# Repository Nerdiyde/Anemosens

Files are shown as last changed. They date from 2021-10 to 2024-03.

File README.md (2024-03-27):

# Anemosens

Anemosens is an 3D printable anemometer that mostly consists of SLA printed parts.

  **Meanwhile I improved the initial design files. The latest design files are available here:**
     https://nerdiy.de/de_de/produkt/anemosens-v1-1-teile-fuer-3d-druckbares-anemometer-3d-druckbar-stl-dateien/

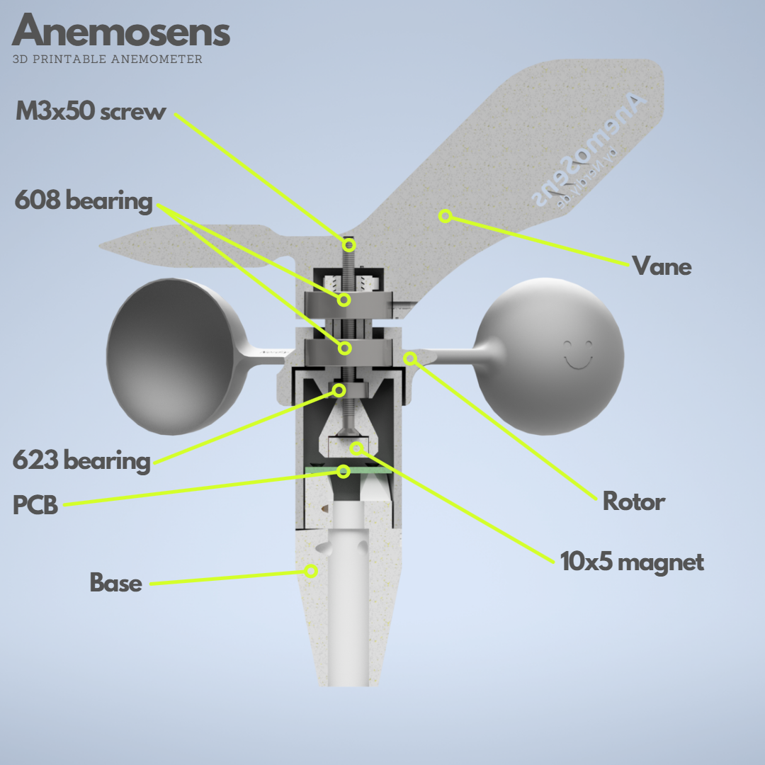
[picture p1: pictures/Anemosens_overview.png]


## Detailed build guide

**You can find more information and detailed HowTo's in the following articles:**

- [Anemosens - Build a 3D printed wind sensor / anemometer](https://nerdiy.de/en/howto-anemosens-ein-3d-gedruckten-windsensor-anemometer-aufbauen/)

Anemosens_Video (https://www.youtube.com/watch?v=w3RU5c9Zf3Q)

## MCU PCB

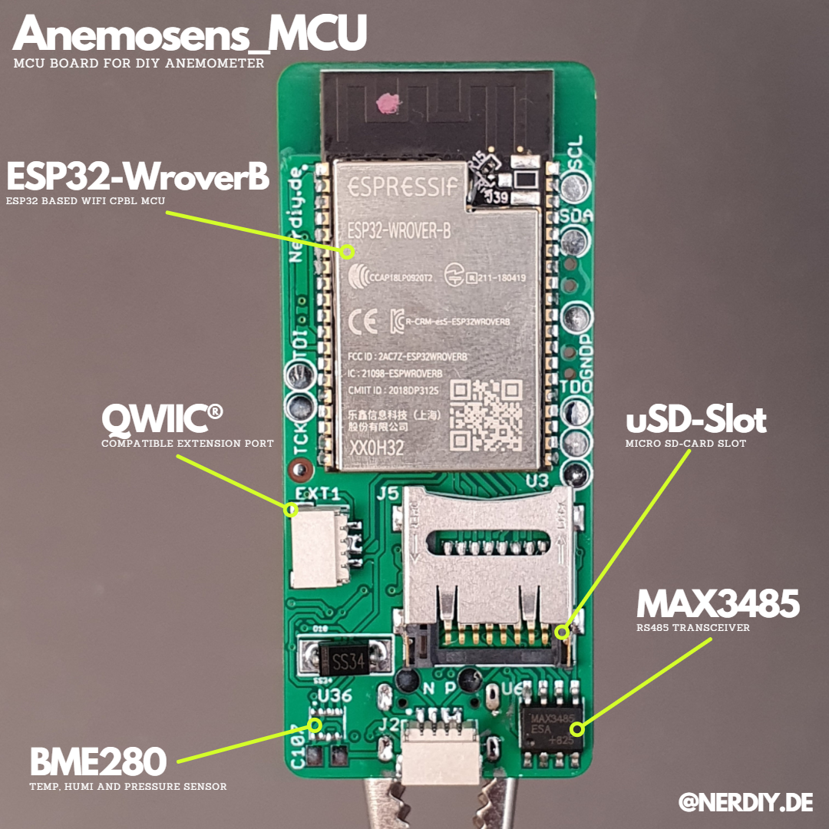
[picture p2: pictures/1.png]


Thanks to the MCU Board it will be possible to use Anemosens as a standalone Anemometer that can be used for long time observations in remote areas (therefore the microSD-card slot) or just as one part of your weatherstation (therefore the RS485 interface).

The RS485 interface is used to make the measured data available via Modbus. This way you can connect the Anemometer easily to your RaspberryPi, PC or many other platforms that support RS485/Modbus.

Additionally you can activate a serial-stream of the data (packed as handy JSON) via the USB connection.

Last but not least the integrated ESP32 also opens a BLE Server. Thanks to this you also have the possibility to pull the data wirelessly using your smartphone or computer.

Of course you can also write your own firmware and program it via the integrated USB-C port. The QWIIC-port makes it easy to connect additional sensors via I2C.

**You can find more information about the sensor pcb in the following article:**

- [PCB - Assembly of the Anemosens_MCU PCB](https://nerdiy.de/en/howto-pcb-anemosens_mcu-pcb-aufbauen/)

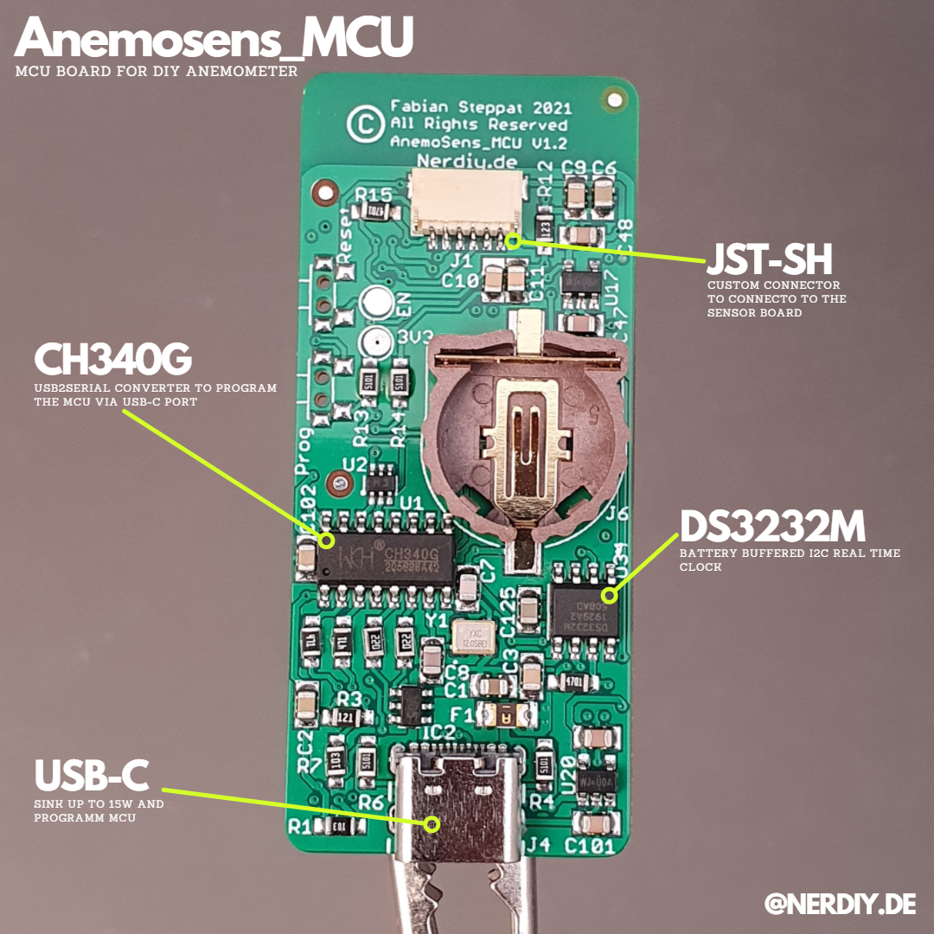
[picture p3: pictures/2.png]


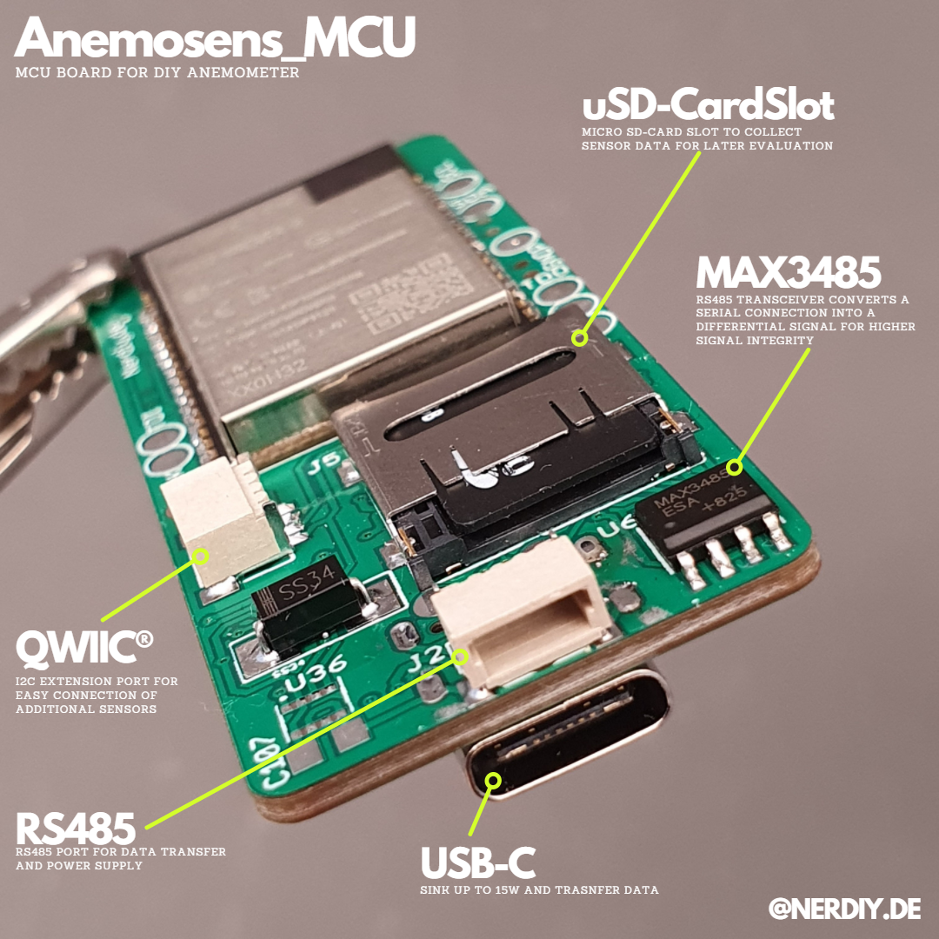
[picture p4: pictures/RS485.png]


## Sensor PCB

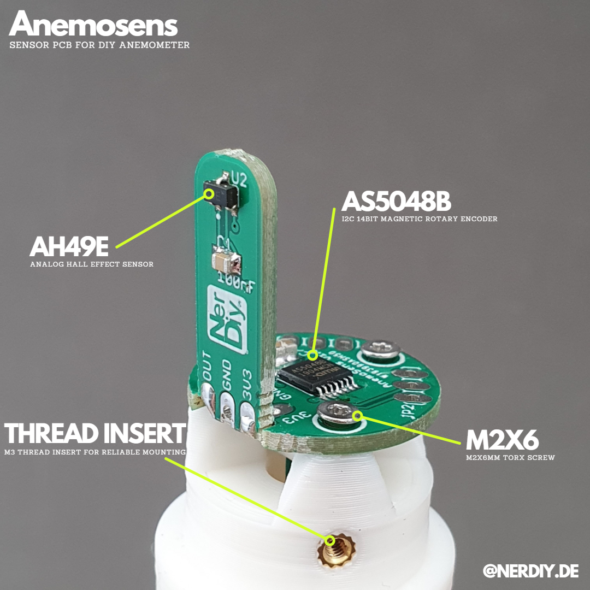
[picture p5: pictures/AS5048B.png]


The Anemosens sensor PCB is the basis for the sensor assembly of Anemosens, a 3D printed anemometer that I developed for the second version of WinDIY. (article here: **_[https://nerdiy.de/en/howto-pcb-das-anemosens-sensor-pcb-aufbauen//](https://nerdiy.de/en/howto-pcb-das-anemosens-sensor-pcb-aufbauen/)_**).

For this purpose, an AH49E Hall sensor and an AS5048B I2C 14 bit magnetic rotary encoder are installed on the PCB. The AS5048B is used to determine the wind direction. With the help of the AH49E Hall sensor you can measure the wind speed by measuring the time of one complete revolution of the wind blades.

To finish the assembly of the PCB you need to divide it into two parts and solder it together at a 90� angle. The finished PCB can then mounted into the 3D printed housing from Anemosens and fixed with three M2x6 screws.

**You can find more information about the sensor pcb in the following article:**

- [PCB - Assemble the Anemosens sensor PCB](https://nerdiy.de/en/howto-pcb-das-anemosens-sensor-pcb-aufbauen/)

### Trademarks

All third-party trademarks are the property of their respective owners. More infos here: https://nerdiy.de/en/warenzeichen/

### License

Unless otherwise stated, all works presented here and on Nerdiy.de that are not based on software/code are subject to the CC BY-NC-SA 4.0 license (attribution - non-commercial - dissemination under the same conditions 4.0 international).

You can find additional infos here: https://nerdiy.de/en/lizenz/

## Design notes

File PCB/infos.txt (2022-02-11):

Additonal build instructions:

MCU PCB:
English: https://nerdiy.de/en/howto-pcb---anemosens_mcu-pcb-aufbauen/
German: https://nerdiy.de/howto-pcb---anemosens_mcu-pcb-aufbauen/

Sensor PCB:
English: https://nerdiy.de/en/howto-pcb-das-anemosens-sensor-pcb-aufbauen/
German: https://nerdiy.de/howto-pcb-das-anemosens-sensor-pcb-aufbauen/

The PCBs can be ordered at:
https://www.pcbway.com/project/shareproject/Anemosens_MCU.html
https://www.pcbway.com/project/shareproject/Anemosens_sensor_PCB.html

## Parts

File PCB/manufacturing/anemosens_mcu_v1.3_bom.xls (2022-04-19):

PCBWay Bom Quotation, Product No.:T-1C4W457044A
Item # | *Designator | *Qty | Manufacturer | *Mfg Part # | Description / Value | *Package/Footprint | *Unit Price(5 sets) | *Total | *Delivery Time | *Actual Purchase Mfg Part # | *PCBWay Note | Customer Reply | PCBWay Update | Comment
1 | C2,C3,C9,C10,C102,C107,C125 | 7 |  |  | 100nF | C0805K | $0.031 | $1.085 |  | CL21B104KCFNNNE | 『 』
2 | C47,C48,C101,C103 | 4 |  |  | 1µF | C0805K | $0.029 | $0.580 |  | CL21B105KBFNNNE | 『 』
3 | C1,C6 | 2 |  |  | 10uF | C0805K | $0.060 | $0.600 |  | CL21A106KOQNNNE | 『 』
4 | C7,C8 | 2 |  |  | 22pF | C0805K | $0.074 | $0.740 |  | CL21C220JBANNNC | 『 』
5 | C11 | 1 |  |  | 1nF | C0805K | $0.242 | $1.210 |  | CL21C102JBCNNNC | 『 』
6 | R1,R7 | 2 |  |  | 10k | R0805W | $0.030 | $0.300 |  | RC0805FR-0710KL | 『 』
7 | R4,R6 | 2 |  |  | 5,1k | R0805W | $0.031 | $0.310 |  | RC0805FR-075K1L | 『 』
8 | R10,R11 | 2 |  |  | 66 | R0805W | $0.031 | $0.310 |  | RC0805FR-0766RL | 『 』
9 | R13,R14 | 2 |  |  | 5k | R0805W | $0.031 | $0.310 |  | RC0805FR-075KL | 『 』
10 | R15,R16 | 2 |  |  | 4k7 | R0805W | $0.035 | $0.350 |  | RC0805FR-074K7L | 『 』
11 | R45,R47 | 2 |  |  | 470 | R0805W | $0.032 | $0.320 |  | RC0805FR-07470RL | 『 』
12 | R3 | 1 |  |  | 120 | R0805W | $0.066 | $0.330 |  | RC0805FR-07120RL | 『 』
13 | R12 | 1 |  |  | 12k | R0805W | $0.050 | $0.250 |  | RC0805FR-0712KL | 『 』
14 | D10 | 1 | MDD | SS34 | SS34 | SMADIODE | $0.110 | $0.550 |  |  | 『 』
16 | U36 | 1 |  | BME280 | BME280 | PSON65P250X250X100-8N | $7.700 | $38.500 |  |  | 『 』[Price is changing higher, final price should be subjected to the real price when order!] |  |  | Optional: Only needed if measurement of temperature, humidity and air pressure is needed
17 | U$22,U$23 | 2 |  |  | SMT2X4MMTACTILE_PUSH_BUTTON | SMT2X4MMTACTILE_PUSH_BUTTON |  |  |  |  | 『 』Please provide exact part number or component URL. |  |  | Optional: Only needed if programming of the ESP32 is done manually (not via the USB-C connection)
18 | U6 | 1 |  | MAX3485ESA+ | MAX3485ESA+ | SOIC127P600X175-8N | $1.470 | $7.350 |  |  | 『 』 |  |  | Optional: Only needed if communication via rs485/modbus is needed
19 | U34 | 1 |  | DS3232M | DS3232M | SOIC127P600X175-8N | $9.500 | $47.500 |  |  | 『 』[Price is changing higher, final price should be subjected to the real price when order!] |  |  | Optional: Only needed for Timekeeping if data logging on locally connected micro SD card is needed
20 | U1 | 1 |  | CH340G | CH340G | SOIC16 | $0.825 | $4.125 |  |  | 『 』
21 | U2 | 1 |  | UMH3N | UMH3N | SOP65P210X100-6N | $0.156 | $0.780 |  |  | 『 』
22 | U17,U20 | 2 |  | RT9013 | RT9013 | SOT23-5 | $0.417 | $4.170 |  | RT9013-33GB | 『 』
23 | U3 | 1 |  | ESP32-WROVER-B | ESP32-WROVER-B | XCVR_ESP32-WROVER-B_(16MB) | $5.360 | $26.800 |  | ESP32-WROVER-B(16MB) | 『 』[Price is changing higher, final price should be subjected to the real price when order!]
24 | Y1 | 1 |  | ABM8AIG-12.000MHZ-12-2Z-T3 | ABM8AIG-12.000MHZ-12-2Z-T3 | OSCSC320X250X100N | $1.308 | $6.540 | 7-10 Workdays |  | 『 』
25 | F1 | 1 |  | 1206L200PR | 4A | PTC-1206-WIDE |  |  |  |  | 『 』
26 | EXT1 | 1 |  | SM04B-SRSS-TB(LF)(SN) | MICROBUILDER_STEMMA_I2C_QT | JST_SM04B-SRSS-TB(LF)(SN) |  |  |  |  | 『 』
28 | IC2 | 1 | TECH PUBLIC | SRV05-4 | SRV05-4 | TSOP-6.PAC | $0.152 | $0.760 |  |  | 『 』
29 | J4 | 1 |  | USB4105_REVA | USB4105_REVA | GCT_USB4105_REVA | $1.059 | $5.295 | 7-10 Workdays | USB4105-GF-A | 『 』
30 | J2 | 1 |  | SM04B-SRSS-TB(LF)(SN) | SM04B-SRSS-TB(LF)(SN) | JST_SM04B-SRSS-TB(LF)(SN) | $0.260 | $1.300 |  |  | 『 』 |  |  | Optional: Only needed if communication via rs485/modbus is needed
31 | J1 | 1 |  | SM06B-SRSS-TB(LF)(SN) | SM06B-SRSS-TB(LF)(SN) | JST_SM06B-SRSS-TB(LF)(SN) | $0.552 | $2.760 |  |  | 『 』
32 | J6 | 1 |  | BC501SM-TR | BC501SM-TR | MPD_BC501SM-TR | $1.714 | $8.570 | 7-10 Workdays |  | 『 』
33 | J5 | 1 |  | MEM2067-02-180-00-A | TRANSFLASH-LOCK | TRANSFLASH-LOCK-SOCK |  |  |  |  | 『 』 |  |  | Optional: Only needed if data logging on a locally inserted sd card is needed.
 |  |  |  |  |  |  | All Total | $161.695

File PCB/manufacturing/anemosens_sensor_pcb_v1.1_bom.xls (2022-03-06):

PCBWay Bom Quotation, Product No.:T-1C6W457044A
Item # | *Designator | *Qty | *Mfg Part # | Description / Value | *Package/Footprint | *Unit Price(5 sets) | *Total | *Delivery Time | *Actual Purchase Mfg Part # | *PCBWay Note | Customer Reply | PCBWay Update | Comment
1 | C1,C7 | 2 |  | 100nF | C0805K | $0.032 | $0.320 |  | CL21B104KBCNNNC | 『 』
2 | C8 | 1 |  | 10uF | C0805K | $0.121 | $0.605 |  | CL21A106KOQNNNE | 『 』
4 | U1 | 1 | AS5048B-HTSP | AS5048B-HTSP | SOP65P640X120-14N | $9.718 | $48.590 | 7-10 Workdays |  | 『 』
5 | U2 | 1 | AH49E | AH49E | SOT91P240X105-3N | $0.228 | $1.140 |  |  | 『 』
6 | JP1,JP2 | 2 |  |  | 1X03 |  |  |  |  | 『 』Please provide exact part number or component URL. |  |  | Do not populate! This are solder pads only used for development purposes. (Same signals are available on J1)
7 | J1 | 1 | BM06B-SRSS-TB(LF)(SN) | BM06B-SRSS-TB(LF)(SN) | JST_BM06B-SRSS-TB(LF)(SN) | $0.437 | $2.185 |  |  | 『 』
 |  |  |  |  |  | All Total | $52.840

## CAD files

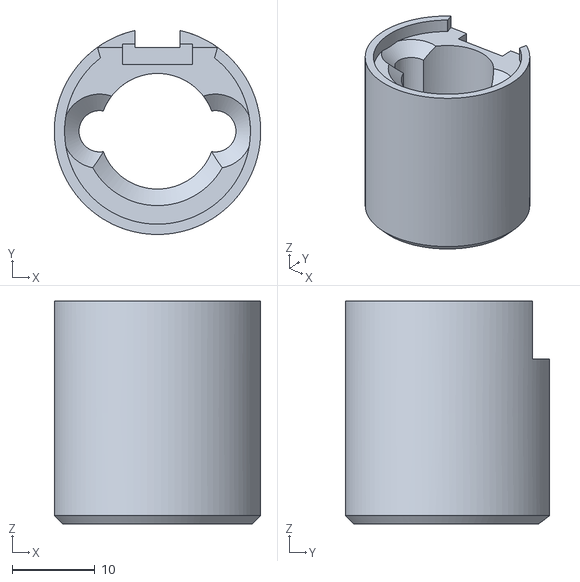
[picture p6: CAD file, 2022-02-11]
STLs/pcb_assembly_jig_V1.0.stl
25.0 x 24.7 x 27.0

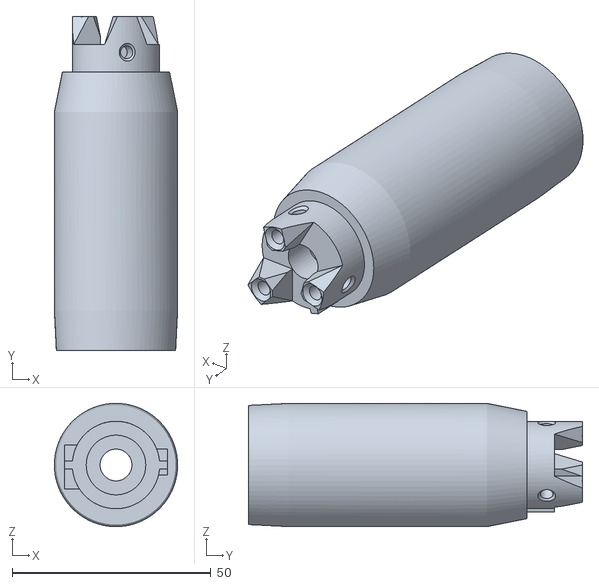
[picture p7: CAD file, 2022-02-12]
STLs/mount_base_mcu_board_V1.1.stl
31.0 x 84.0 x 31.0

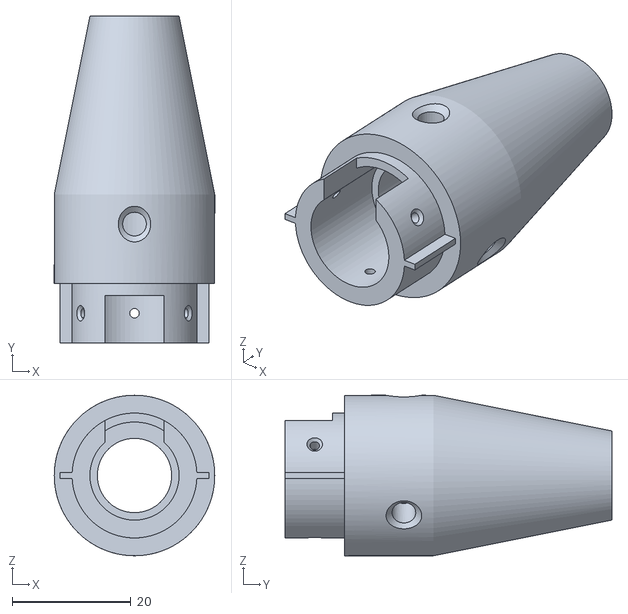
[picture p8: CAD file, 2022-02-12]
STLs/mount_base_mcu_board_bottom_cap_fdm_printed_V1.0.stl
27.0 x 55.0 x 27.0

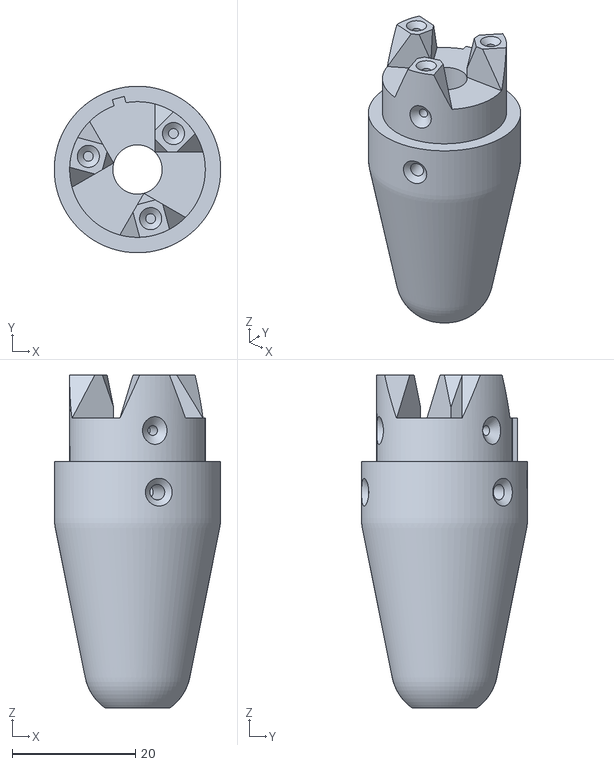
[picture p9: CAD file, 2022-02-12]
STLs/mount_base_10mm_pipe_sla_printed_V1.0.stl
27.0 x 27.0 x 54.0

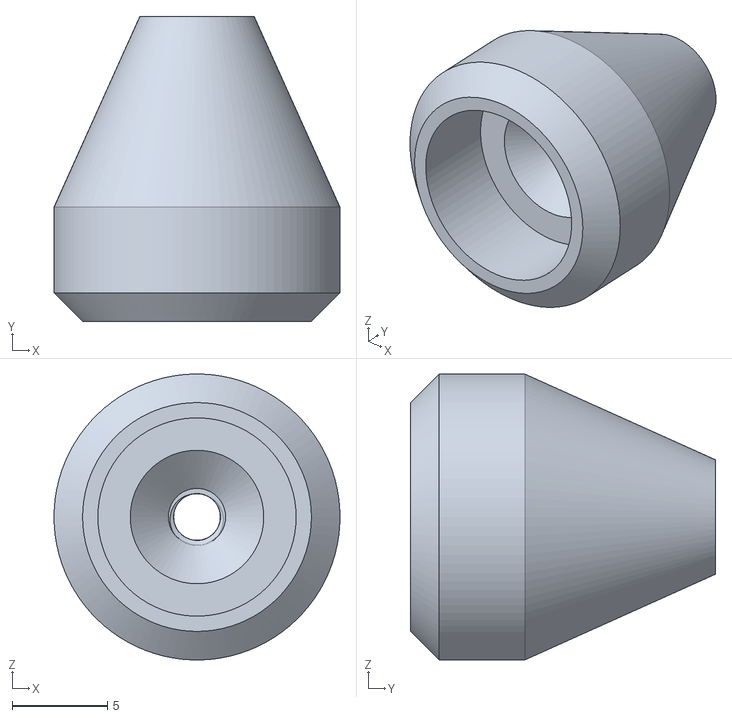
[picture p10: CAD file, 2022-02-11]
STLs/dir_magnet_base_V1.0.stl
15.0 x 16.0 x 15.0

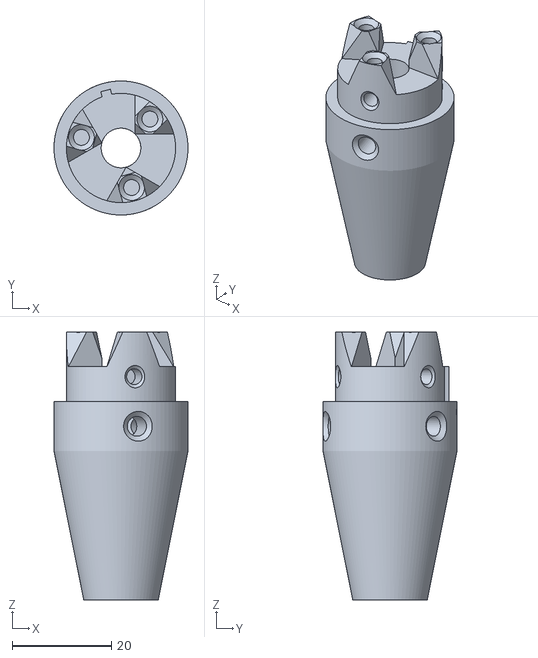
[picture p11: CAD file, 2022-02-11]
STLs/mount_base_10mm_pipe_fdm_printed_V1.0.stl
27.0 x 27.0 x 54.0

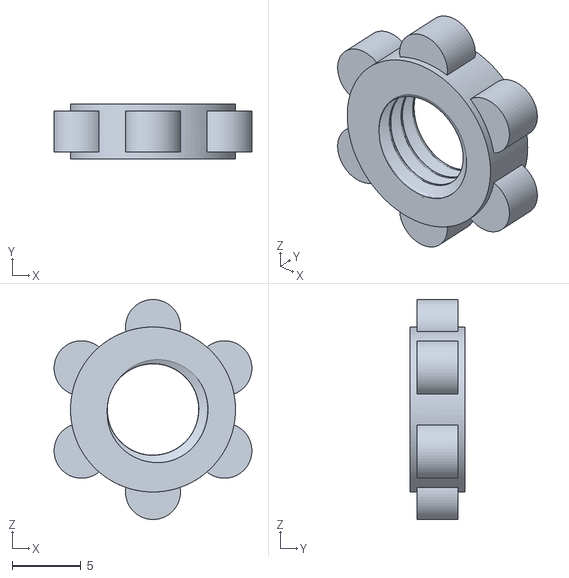
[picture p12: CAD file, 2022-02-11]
STLs/bearing_clamp_V1.0.stl
14.4 x 4.00 x 16.0

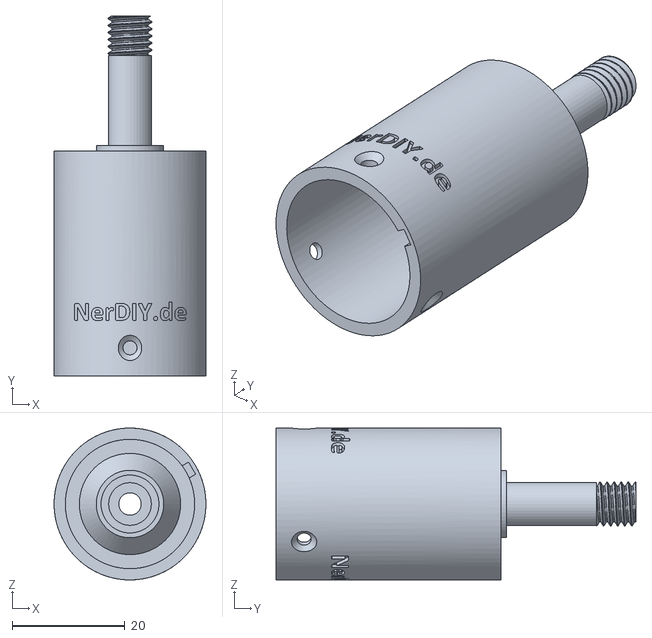
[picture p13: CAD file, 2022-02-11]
STLs/base_V1.1.stl
27.0 x 64.0 x 27.0

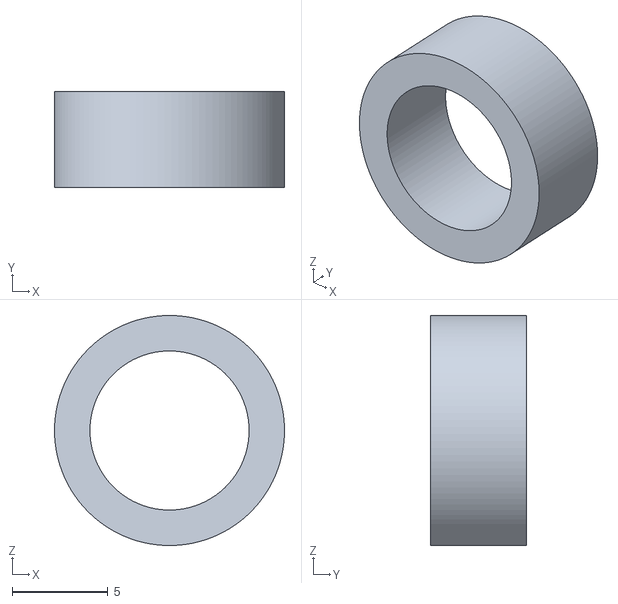
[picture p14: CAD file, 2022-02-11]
STLs/dir_sens_bearing_distance_ring_V1.0.stl
12.0 x 5.00 x 12.0

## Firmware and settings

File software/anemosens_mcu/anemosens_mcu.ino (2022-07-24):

/*                                 _   _                 _  _               _
                                 | \ | |               | |(_)             | |
  __      ____      ____      __ |  \| |  ___  _ __  __| | _  _   _     __| |  ___
  \ \ /\ / /\ \ /\ / /\ \ /\ / / | . ` | / _ \| '__|/ _` || || | | |   / _` | / _ \
   \ V  V /  \ V  V /  \ V  V /_ | |\  ||  __/| |  | (_| || || |_| | _| (_| ||  __/
    \_/\_/    \_/\_/    \_/\_/(_)|_| \_| \___||_|   \__,_||_| \__, |(_)\__,_| \___|
                                                               __/ |
                                                              |___/
     Anemosens_MCU firmware by Fabian Steppat
     Infos on www.nerdiy.de/anemosens

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
     You should have received a copy of the GNU General Public License
     along with this program.  If not, see <http://www.gnu.org/licenses/>.
*/

/*ToDO:
   sd karte: Automatische archivierung der messwerte, ausgabe der messwerte über usb
   rtc: Einstellung der Zeit über USB, Autoamtische konfiguration der Uhrzeit zur Kompilierzeit
   bme280: Auslesen der Daten, Ausgabe über USB auf Anfrage, Optional kann die speicherung der Werte auf der SD Karte aktiviert werden
   RS485: Modbusfunktionalität: Daten werden über RS485 zur Verfügung gestellt.
   ausgabe der gesammelten daten über serial connection
   SPIFFS: Daten können im SPiffs gespeichert werden
   Ringspeicherfunktion (auf SD-Karte speichern, falls keine SD Karte vorhanden im internen/externen Flash speichern)
   esp web tools zum flashen auf nerdiy.de zur verfügung stellen
*/

//Wind direction sensing
#include <ams_as5048b.h>
#include <ArduinoJson.h>

//SD card
#include "FS.h"
#include "SD.h"
#include "SPI.h"

//RTC
#include "RTClib.h"

//BME280 climate sensor
#include <Adafruit_Sensor.h>
#include <Adafruit_BME280.h>

//Modbus
#include <ModbusRTU.h>

//BLE server
#include <BLEDevice.h>
#include <BLEUtils.h>
#include <BLEServer.h>

//Config stuff
#include "_config.h"
#include "_defs.h"


//Control settings

/*
  Available data:
  - RTC Time
  - RTC Temperature in °C
  - Wind speed in m/s
  - Wind speed in bft
  - Wind speed as string
  - Wind direction
  - BME280 temperature in °C
  - BME280 humidity in rel%
  - BME280 air pressure in hPa
  - Uptime

  Possible settings:
  - SD card logging activated/deactivated
  - SD card ring storage activated/deactivated
  - Periodic JSON output via USB-serial-connection activated/deactivated
  - Serial report period in ms
  - BLE data server activated/deactivated
  - Set current wind direction to zero degrees
  - Set RS485 baudrate
  - Restart device
  - Set RTC time

*/

void setup() {
  init_serial();
  print_esp32_chip_id();

  init_wind_direction_sensor();
  init_wind_speed_sensor();
  init_rs485();
  init_sd_card();
  init_bme280();
  init_rtc();
  init_ble_server();
}

void loop()
{
  handle_rs485();
  //update_ble_server_values();

  /*
    Measure sensor data
  */

  // update wind direction sensor data
  if (regular_execution(&wind_dir_last_moving_average_update_timestamp, WIND_DIR_MOVING_AVERAGE_UPDATE_PERIOD))
  {
    update_wind_dir_moving_average();
  }

  // update wind speed sensor data
  update_wind_speed_moving_average();

  /*
    Evaluate measured sensor data
  */
  if (regular_execution(&wind_dir_last_evaluation_timestamp, WIND_DIR_EVALUATION_PERIOD))
  {
    wind_direction = read_wind_dir_moving_average();
  }

  if (regular_execution(&wind_speed_last_evaluation_timestamp, WIND_SPEED_EVALUATION_PERIOD))
  {
    float rotationsCounter = (float)wind_speed_tick_counter / (float)SPEED_MAGNETS_COUNT; // because there are three magnets the total amount of ticks need to be devided by the amount of magnets
    float rotations_per_second = rotationsCounter * (1000.0 / (float)WIND_SPEED_EVALUATION_PERIOD); // calculate the rotations per second
    float rotations_per_minute = rotations_per_second * SECONDS_PER_MINUTE;
    windspeed_in_meter_per_second = (rotations_per_minute * CONSTANT_PI * WIND_SPEED_SENSOR_SHOVELS_DIAMETER) / SECONDS_PER_MINUTE;
    wind_speed_tick_counter = 0;
  }

  /*
    Update and send measured sensor data
  */
  if (regular_execution(&last_data_report_timestamp, DATA_REPORT_PERIOD))
  {
    if (send_data_via_serial_acivtated)
    {

      StaticJsonDocument<200> output;

      if (rtc_initialized)
      {
        output["time"] = return_human_readable_time_ds3232m();
        output["temp_rtc"] = return_rtc_temperature();
      }

      output["dir_deg"] = wind_direction;
      output["dir_com"] = convert_degree_to_compass(wind_direction);

      if (wind_speed_measurement_is_ready())
      {
        output["m/s"] = windspeed_in_meter_per_second;
        output["bft"] = convert_meter_per_second_to_bft(windspeed_in_meter_per_second);
        output["string"] = convert_meter_per_second_to_wind_strength(windspeed_in_meter_per_second);
      }

      if (bme280_is_running())
      {
        output["temp_bme"] = serialized(String(return_temperature_bme280(), 2));
        output["humi"] = serialized(String(return_humidity_bme280(), 2));
        output["pressure"] = serialized(String(return_pressure_bme280(), 2));
        output["alt"] = serialized(String(return_altitude_bme280(), 2));
      }

      serializeJsonPretty(output, Serial);
    }

    update_rs485_register_values();
  }


}

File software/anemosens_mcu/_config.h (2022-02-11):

/*                                 _   _                 _  _               _
                                 | \ | |               | |(_)             | |
  __      ____      ____      __ |  \| |  ___  _ __  __| | _  _   _     __| |  ___
  \ \ /\ / /\ \ /\ / /\ \ /\ / / | . ` | / _ \| '__|/ _` || || | | |   / _` | / _ \
   \ V  V /  \ V  V /  \ V  V /_ | |\  ||  __/| |  | (_| || || |_| | _| (_| ||  __/
    \_/\_/    \_/\_/    \_/\_/(_)|_| \_| \___||_|   \__,_||_| \__, |(_)\__,_| \___|
                                                               __/ |
                                                              |___/
     Anemosens_MCU firmware by Fabian Steppat
     Infos on www.nerdiy.de/anemosens

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
     You should have received a copy of the GNU General Public License
     along with this program.  If not, see <http://www.gnu.org/licenses/>.
*/



//Serial
#define BAUDRATE 115200
#define SEND_DATA_VIA_SERIAL_ACTIVATED_STANDARD true

// Wind direction config
#define WIND_DIR_MOVING_AVERAGE_UPDATE_PERIOD 100  //in ms
#define WIND_DIR_EVALUATION_PERIOD 1000  //in ms

//#define WIND_SPEED_UPDATE_TIME 1000

#define HALL_SENS_PIN 33
#define WIND_DIR_SENS_ADDRESS 0x43 //I2C address of the wind direction sensor

// Wind speed config
#define WIND_SPEED_SENSOR_SHOVELS_DIAMETER 0.110 // diameter of the wind shovels in m
#define WIND_SPEED_EVALUATION_PERIOD 1000  //time period between the evaulation and calcluation of the windspeed within in the past period
#define HALL_SENSOR_SAMPLES_COUNT 50  //number of measurements that will be collected to calcualte the average hall sensor value at that time
#define WIND_SPEED_MIN_HALL_SENSOR_VALUE_STANDARD 1600  // this is the standard value for the lowest hall sensor value. It will be automatically adapted during the first rotations of the speed sensor shovels 
#define WIND_SPEED_MAX_HALL_SENSOR_VALUE_STANDARD 1800    // this is the standard value for the biggest hall sensor value. It will be automatically adapted during the first rotations of the speed sensor shovels 
#define SPEED_MAGNETS_COUNT 3 // this is the number of magnets that are attached to the speed sensor shovels
#define SPEED_SENSOR_EDGE_DETECTION_LIMIT 5 // This is the value the moving average of the sensor deviation needs to reach to detect the rising edge

#define WIND_SPEED_STEP_SIZE_MOVING_AVERAGE_READINGS_COUNT 10  // size of the moving average for the wind speed step_size

#define WIND_SPEED_MS_TO_KM_H_CONVERSION_FACTOR 3.6
#define WIND_SPEED_MEASUREMENT_NOT_READY_VALUE 999

//RS485

#define RS485_BAUDRATE 19200
#define RS485_SERIAL_ID 2
#define RS485_RTS_PIN 25 //TX/RX selection pin
#define RS485_TX_PIN_VALUE HIGH
#define RS485_RX_PIN_VALUE LOW
#define RS485_RX_PIN        13
#define RS485_TX_PIN        4
#define STANDARD_RS485_DEVICE_ADDRESS 1

//Read only registers: "Input register"
#define INPUT_REGISTER_ADDRESS_WIND_SPEED_M_S 0
#define INPUT_REGISTER_ADDRESS_WIND_SPEED_K_M_H 1
#define INPUT_REGISTER_ADDRESS_WIND_SPEED_BFT 2
#define INPUT_REGISTER_ADDRESS_WIND_DIRECTION 3
#define INPUT_REGISTER_ADDRESS_TEMPERATURE 4
#define INPUT_REGISTER_ADDRESS_HUMIDITY 5
#define INPUT_REGISTER_ADDRESS_PRESSURE 6

//Read only input: "Discrete Input"
#define DISCRETE_INPUT_REGISTER_ADDRESS_WIND_DATA_READY 0

// misc
#define SECONDS_PER_MINUTE 60.0
#define CONSTANT_PI 3.14159265359
#define DATA_REPORT_PERIOD 500  //in ms

//unit consts
#define U_RAW 1
#define U_TRN 2
#define U_DEG 3
#define U_RAD 4
#define U_GRAD 5
#define U_MOA 6
#define U_SOA 7
#define U_MILNATO 8
#define U_MILSE 9
#define U_MILRU 10


//SD card
#define SD_CS 33
#define SCK 18
#define MISO 19
#define MOSI 23

//RTC DS3232M
#define DS3232M_I2C_ADDRESS 0x68
#define READ_DS3232M_INTERVAL 1000

//BME280 climate sensor

#define BME280_ADDR 0x76
#define SEALEVELPRESSURE_HPA (1013.25)
#define BME280_NOT_RUNNING_VALUE 9999.99
//BLE server
#include <BLEDevice.h>
#include <BLEUtils.h>
#include <BLEServer.h>

//UUIDs generated using https://www.uuidgenerator.net/
#define SERVICE_UUID        "4fafc201-1fb5-459e-8fcc-c5c9c331914b"
#define CHARACTERISTIC_WIND_DIRECTION_UUID "9a768717-51f6-42ec-a8de-346860763756"
#define CHARACTERISTIC_WIND_SPEED_UUID "241d5b75-94b0-4b9e-b3f0-dcb0288e88f6"
#define CHARACTERISTIC_TEMPERATURE_BME_UUID "c9b7139e-6562-4e2e-9d43-a63d0ff98f29"
#define CHARACTERISTIC_SYSTEM_UUID "4739c08d-1e6e-4ec9-9974-55533118504e"
#define BLE_SERVER_NAME      "Anemosens_MCU"

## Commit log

2022-01-30 Add STL files
    [base_V1.1.stl, bearing_clamp_V1.0.stl, dir_magnet_base_V1.0.stl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]
2022-03-06 Add manufacturing files
    [anemosens_mcu_v1.3_bom.xls, anemosens_sensor_pcb_v1.1_bom.xls]
2022-04-19 Add todo
    [anemosens_mcu_v1.3_bom.xls]

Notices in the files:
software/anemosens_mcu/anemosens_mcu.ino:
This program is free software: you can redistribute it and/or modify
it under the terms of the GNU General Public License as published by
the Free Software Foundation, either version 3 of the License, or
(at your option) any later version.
